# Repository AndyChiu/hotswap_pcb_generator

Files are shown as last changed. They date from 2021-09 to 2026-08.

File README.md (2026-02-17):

# 3D列印鍵盤熱插拔板產生器（網路線內芯線版本）

[原作者GitHub: 3D-Printable Hotswap Keyboard PCB Generator](https://github.com/50an6xy06r6n/hotswap_pcb_generator)

此專案為利用3D印表機，列印鍵盤底板、定位板、外殼..等部份來建構鍵盤，由於原作者使用22AWG電源線當主要線路，而我手邊有許多的廢棄網路線，所以就改用網路線內芯線來替代接線，並依照網路線內芯線的尺寸，修改了 switch.scad 的走線方式，因為線材較細，Row與Colum的線路可以走同一面，而不用怕交錯的部份太厚，所以把線路都改到正面走線。

另外也添加了不少種類的軸體，以及MCU等額外鍵盤用零件。

### 額外特性
- 支援多種軸體：Cherry MX-style、MX Low profile、Kailh Choc V1、Choc V2、Choc Mini、Gateron KS27、Gateron KS33 V3、Romer G、Redragon low profile、ALPS
- 單PCB可以放上多種不同軸體，layout.scad可以進行調整
- 支援多種MCU：ProMicro、ProMicro C、Elite C、Pico RP2040、RP2040 Zero
- 支援編碼器：EC11、EVQWGD001
- Choc V2 矮軸可以使用MX規格的衛星軸(穩定器)
- 支援4pin微動開關(microswitch)
- OLED座(0.96" 27.3x27.8mm)
- PCB板可針對外框進行設計，讓PCB板直接當作鍵盤使用
- Choc V1軸、MX軸、KS-27/KS-33與ALPS軸有固定架(holder)的選項可用，用於固定軸體，代替定位板的作用

### 曲面鍵盤設計
- 方式1: [UC36系列](https://github.com/AndyChiu/UC36)中，曲面鍵盤的相關程式與檔案，可由此[查閱](scad_UTP/Curved_PCB_KB)。
- 方式2: PCB板直接可以設定各別軸體的角度與高度，達到曲面鍵盤的效果。

### 限制
因著重在Kailh Choc等矮軸的使用與開發，矮軸上PCB板後高度較低，鍵帽通常也設計的較矮，因此較不易被撥動掉落，直接用 pcb.scad 產生 PCB 板即可使用，所以對於定位板、底板、外殼、墊高等程式檔都沒有更新，因此其他部份使用上可能會有點問題。

### 資料夾/檔案命名
由於對GitHub作業還不是很熟悉，且自己的改太多東西，所以不好直接更動原作者的檔案，因此目前先把自己處理的檔案與資料夾，都加上_UTP後綴字串，相關程式也有調整。

### 元件圖片

#### 軸座 (Switch base)

##### Cherry
| MX-style | MX Low profile |
| --- | --- |
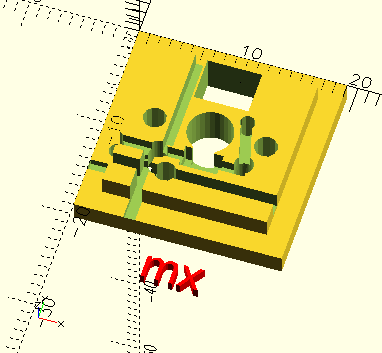
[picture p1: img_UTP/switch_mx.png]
MX
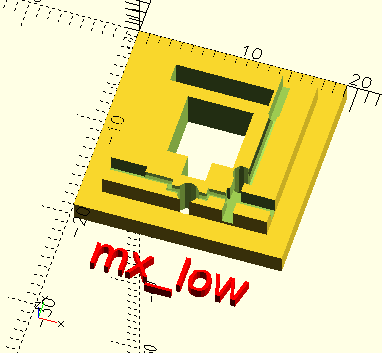
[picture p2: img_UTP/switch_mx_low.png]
MX_Low
| ||

##### Kailh Choc
| Choc V1 | Choc V2 | Choc Mini |
| --- | --- | --- |
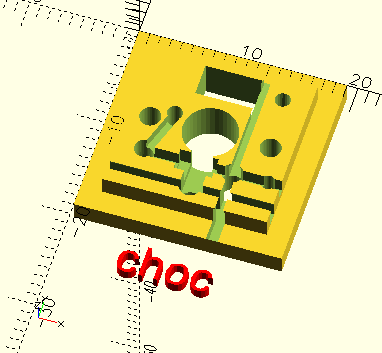
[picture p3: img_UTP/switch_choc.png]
choc
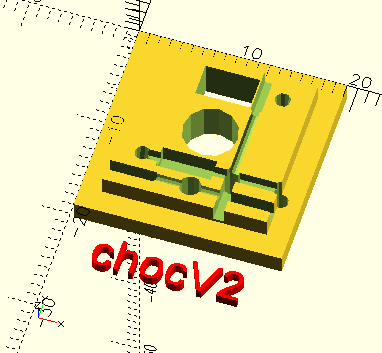
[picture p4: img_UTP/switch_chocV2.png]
chocV2
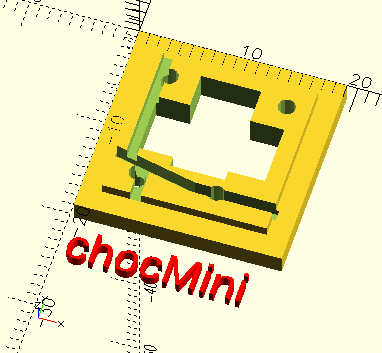
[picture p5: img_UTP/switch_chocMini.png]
chocMini
| |||

##### Kailh Choc
| Gateron KS27 | Gateron KS33 V3 |
| --- | --- |
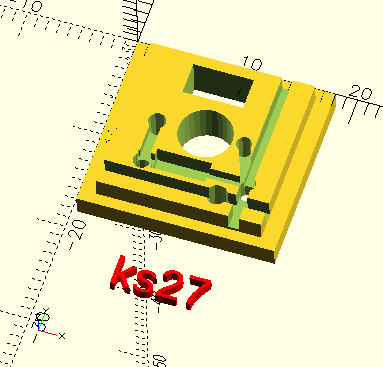
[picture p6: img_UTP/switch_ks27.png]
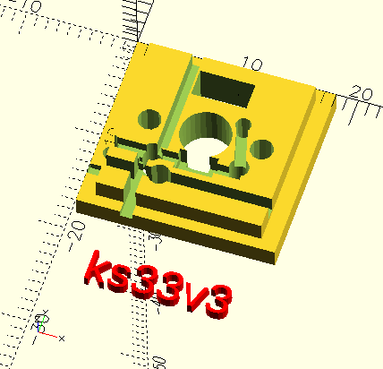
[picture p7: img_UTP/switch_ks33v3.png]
| ||

##### Other
| Romer G | Redragon low profile | ALPS |
| --- | --- | --- |
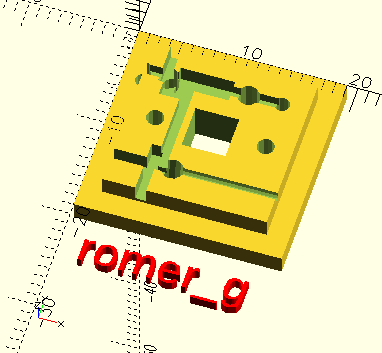
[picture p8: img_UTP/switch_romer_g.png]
Romer G
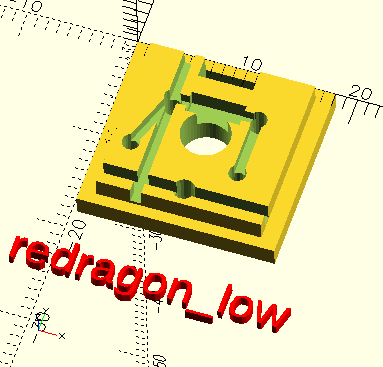
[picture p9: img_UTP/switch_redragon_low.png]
redragon_low
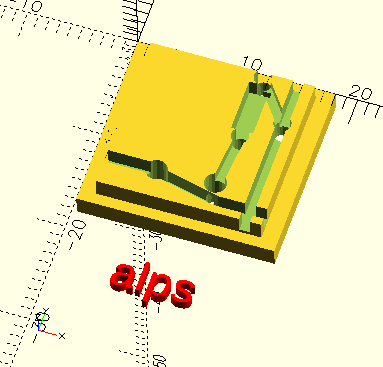
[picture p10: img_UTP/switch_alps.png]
||| |

##### 軸座含固定架
| Cherry MX-style1 | Cherry MX-style2 |
| --- | --- |
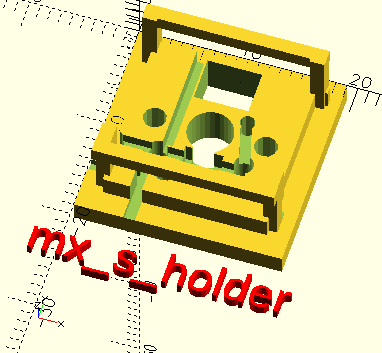
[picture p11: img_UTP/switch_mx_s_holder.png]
switch_mx_holder
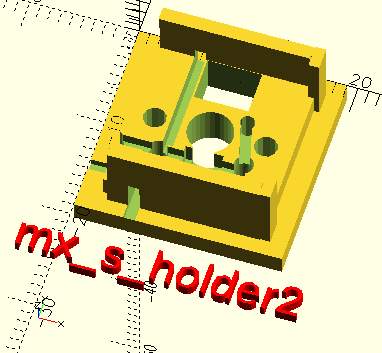
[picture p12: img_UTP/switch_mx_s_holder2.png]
switch_mx_holder
| | |

| Kailh Choc V1 | Gateron KS27| Gateron KS33v3 |
| --- | --- |  --- |
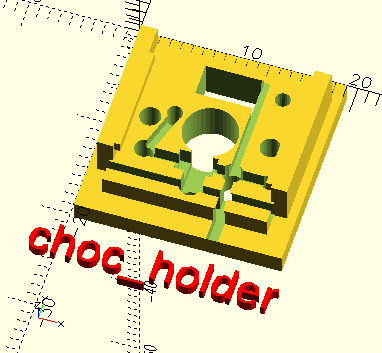
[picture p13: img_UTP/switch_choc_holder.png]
switch_choc_holder
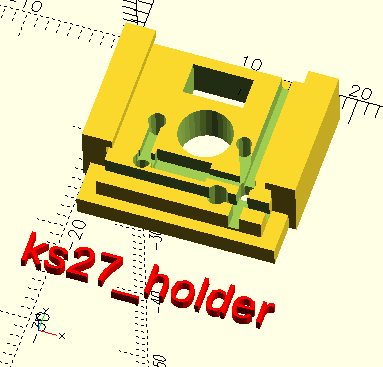
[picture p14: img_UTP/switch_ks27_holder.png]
switch_ks27_holder
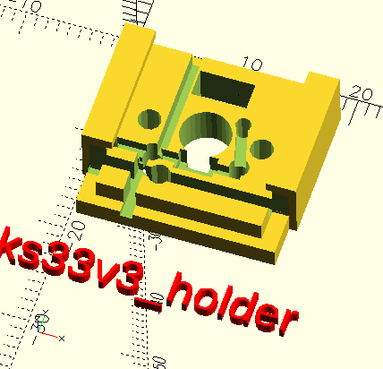
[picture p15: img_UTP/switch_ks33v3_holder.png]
switch_ks33v3_holder
||||

| Redragon low profile | ALPS|
| --- | --- |
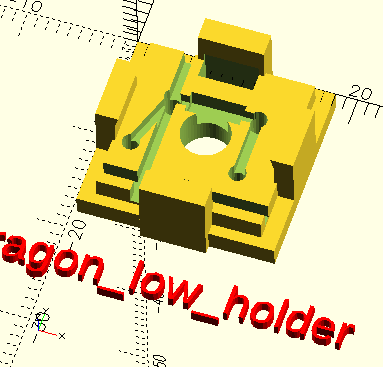
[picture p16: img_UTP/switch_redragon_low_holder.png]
redragon_low_holder
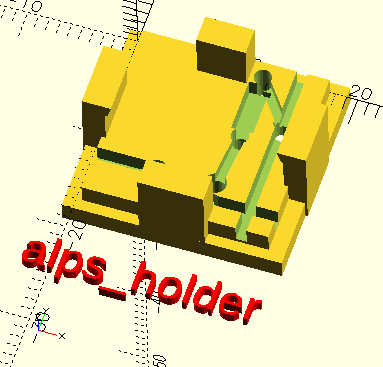
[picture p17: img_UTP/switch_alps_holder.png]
switch_alps_holder
|||

##### Dactyl類型使用的1U PCB
| Kailh Choc V2  |
| -------- |
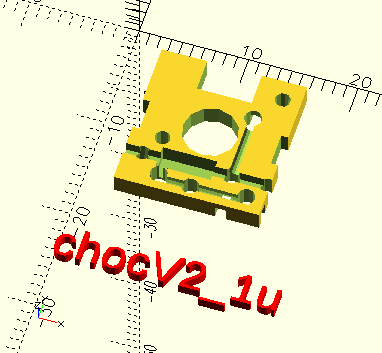
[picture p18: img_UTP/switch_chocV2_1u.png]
switch_chocV2_1u
| |

#### MCU

##### ProMicro

| ProMicro|ProMicro-C|Elite-C|
| --- | --- | --- |
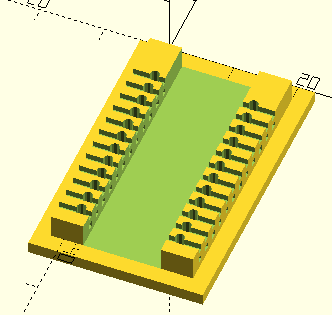
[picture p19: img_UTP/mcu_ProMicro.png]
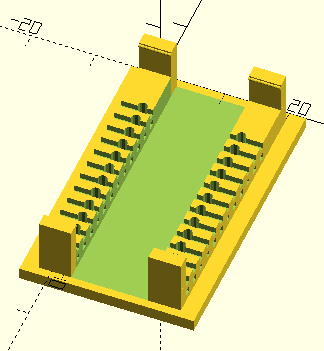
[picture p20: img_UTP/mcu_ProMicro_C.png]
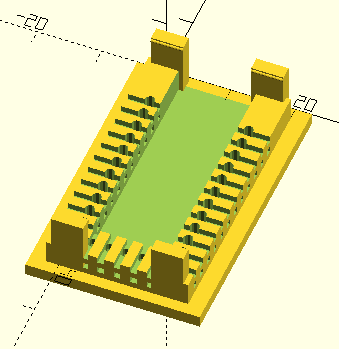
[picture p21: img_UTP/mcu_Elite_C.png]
| |||

##### RP2040

| RP2040 Pico|RP2040 Zero|
| --- |--- |
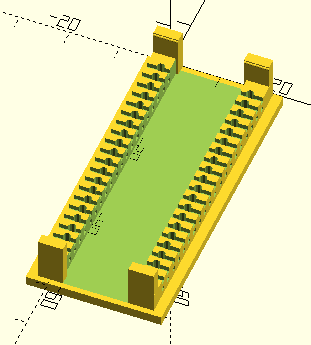
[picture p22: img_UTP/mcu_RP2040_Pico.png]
mcu_RP2040_Pico
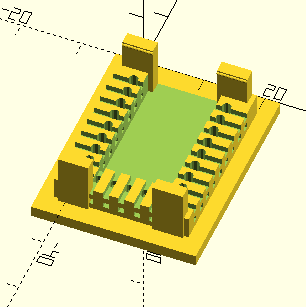
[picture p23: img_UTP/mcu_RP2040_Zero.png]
mcu_RP2040_Zero
| | |

#### 編碼器(Encoder)

|EC11|EVQWGD001|
| --- |--- |
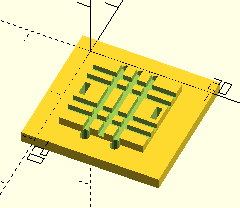
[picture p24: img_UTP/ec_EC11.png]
EC11
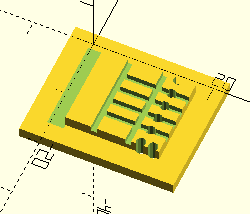
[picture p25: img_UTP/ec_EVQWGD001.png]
EVQWGD001
|||

#### 穩定器(Stabilizer)

|PCB(2u)|PCB Choc V2(2u)|Plate(2u)|
| --- | --- | --- |
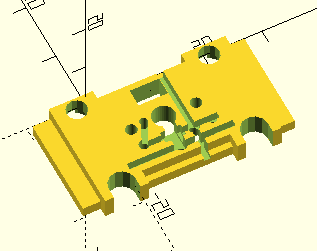
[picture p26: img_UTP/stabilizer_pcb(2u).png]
stabilizer_pcb(2u)
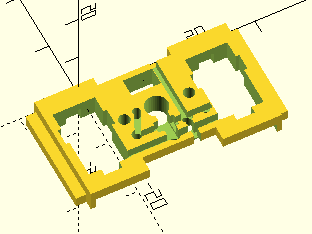
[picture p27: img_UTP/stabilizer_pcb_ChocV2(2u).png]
stabilizer_pcb_ChocV2(2u)
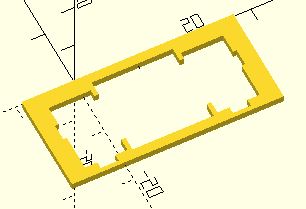
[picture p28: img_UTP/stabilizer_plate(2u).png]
stabilizer_plate(2u)
||||

#### TRRS
|PJ320A|PJ324M|
| --- | --- |
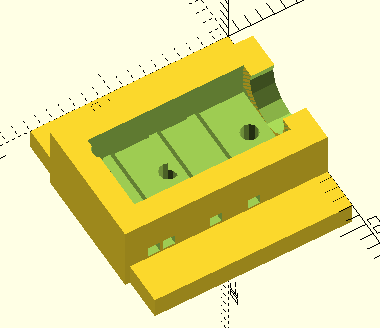
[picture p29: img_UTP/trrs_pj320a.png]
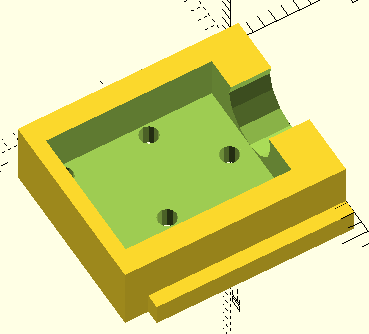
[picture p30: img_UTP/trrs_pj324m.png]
|||

#### 其他
|Micro Switch|OLED 0.96" 27.3x27.8mm|
| --- | --- |
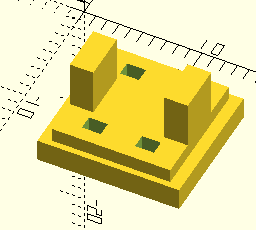
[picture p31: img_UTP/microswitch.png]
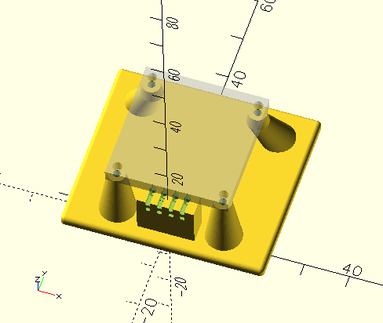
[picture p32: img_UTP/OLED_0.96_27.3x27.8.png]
|||

### 設計
可以優先參考原作者[設計指南(Design Guide)](https://github.com/50an6xy06r6n/hotswap_pcb_generator/blob/main/guide/design_guide.md)

修改版本的前期設計請參考（撰寫中）。

### 組裝
請參閱以下Blog:

[嘗試Choc V2矮軸與拉線教學](https://ie321mx.blogspot.com/2021/09/choc-v2.html)

[關於二極體版本的補充教學](https://ie321mx.blogspot.com/2021/09/blog-post.html)

原作者的[組裝指南(Build Guide)](https://github.com/50an6xy06r6n/hotswap_pcb_generator/blob/main/guide/build_guide.md)

### PCB板宣染圖
PCB板設計時，可以直接設計成曲面
PCB KB Curve Design1
PCB KB Curve Design2

F5宣染時，可以顯示設定的軸體與鍵帽，用來檢查各軸間是否有干擾的情況產生
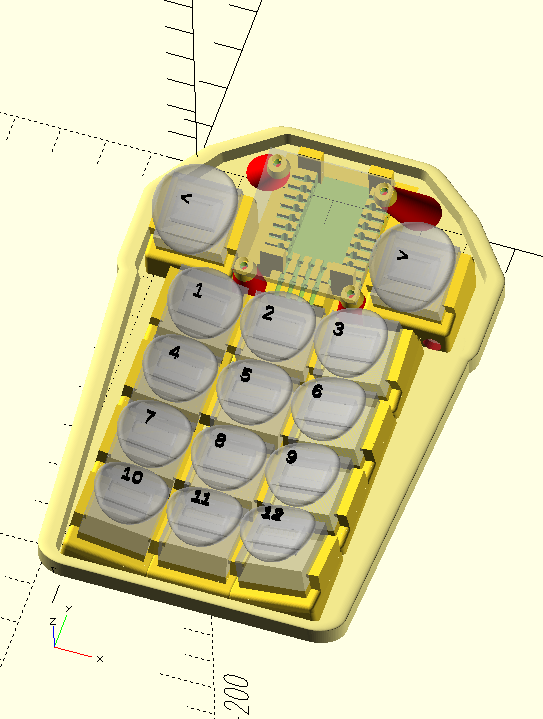
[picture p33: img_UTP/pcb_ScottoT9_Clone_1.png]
PCB - Scotto T9

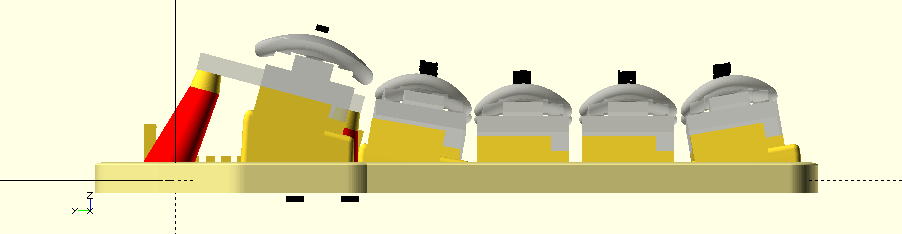
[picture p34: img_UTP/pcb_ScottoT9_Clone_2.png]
PCB - Scotto T9


### 照片集

印出的PCB曲面鍵盤
GMvE2cgXMAA4j0y

上軸體與鍵帽後
GMvKBvrWIAEK0nz

GMvKBzpXUAAMyPL

GMvKB7nXAAAX0QT

改良的EC11編碼器底座
EC11 Base

UC2 鍵盤 Choc V1 軸體 左手
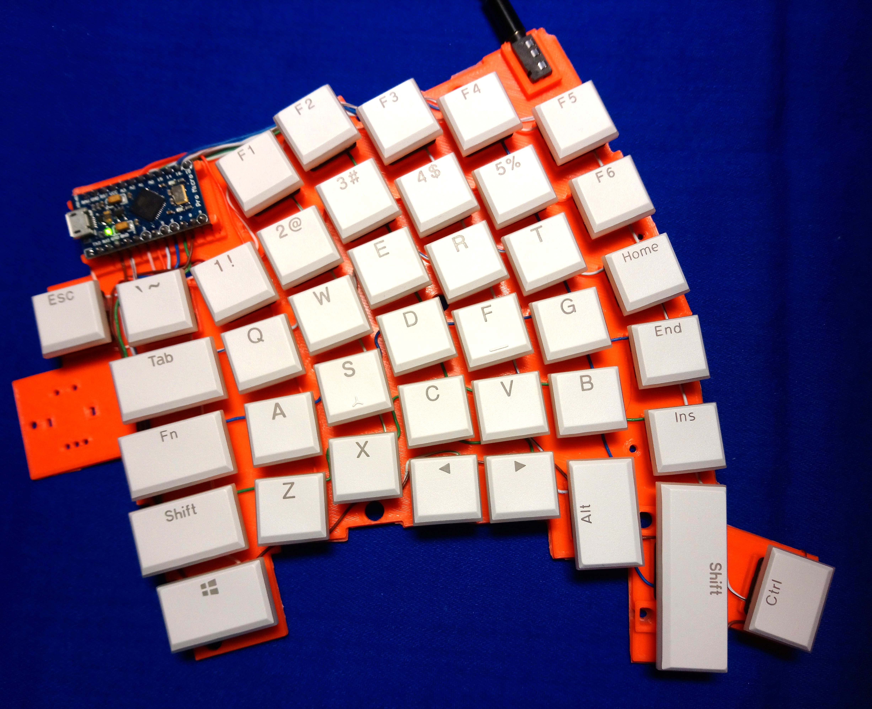
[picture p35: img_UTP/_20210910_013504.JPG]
UC2 Left Hand


UC2 鍵盤 Choc V1 軸體 右手
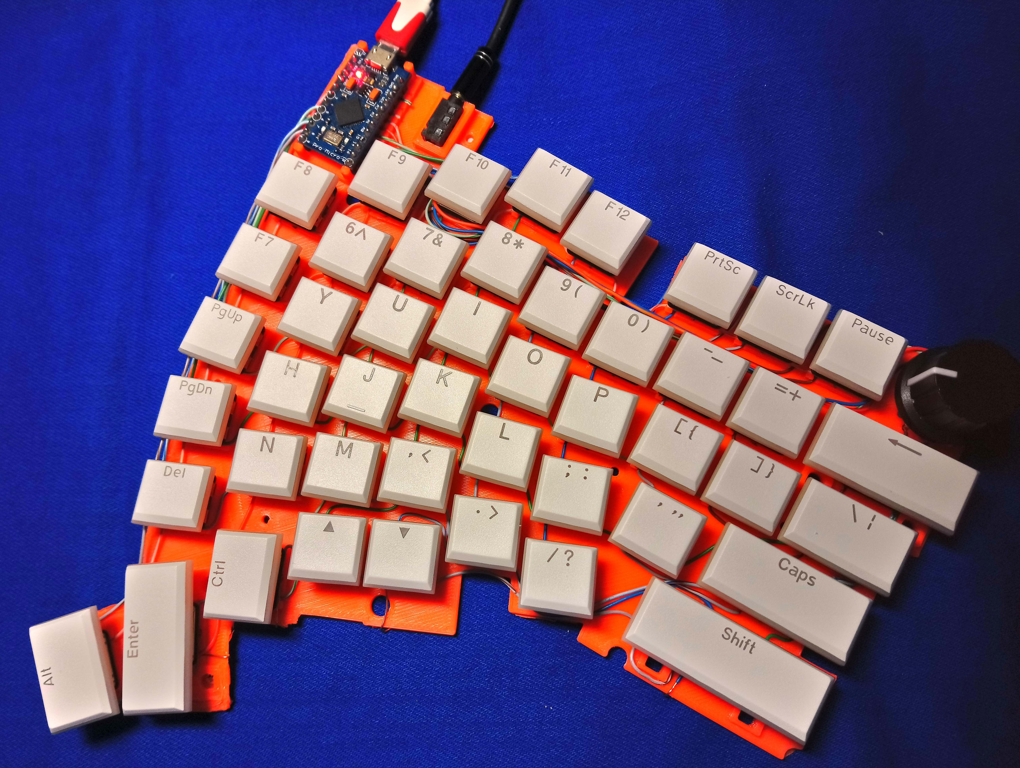
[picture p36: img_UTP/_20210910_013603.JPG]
UC2 Right Hand


EVQWGD001 編碼器
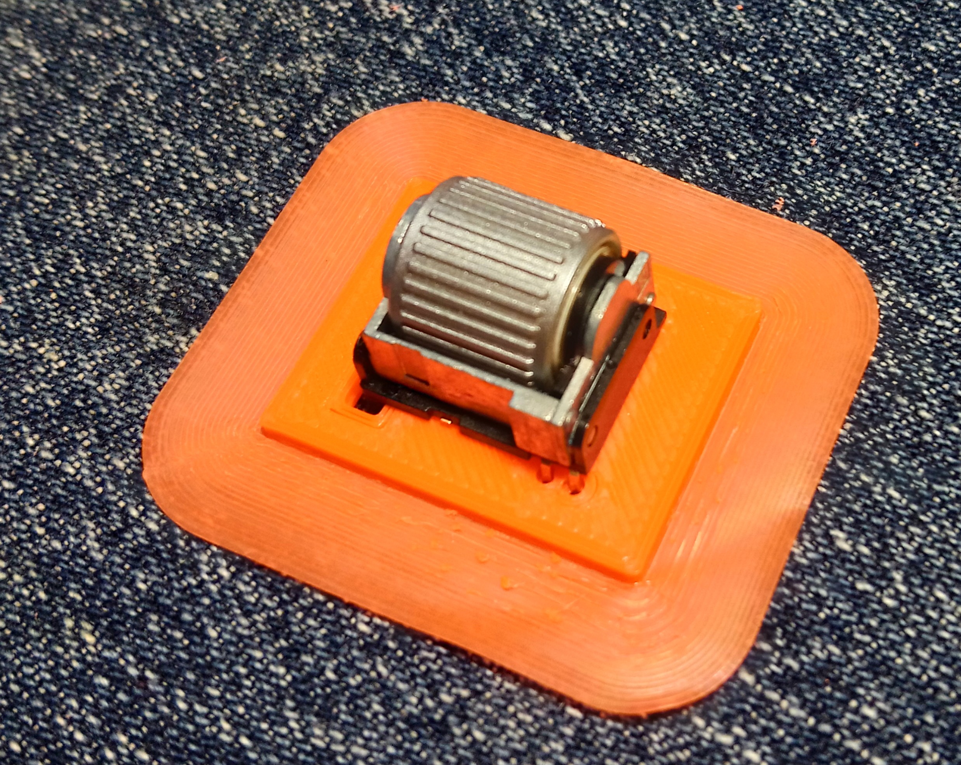
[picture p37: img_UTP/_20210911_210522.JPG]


Choc V1 + V2 軸共用座
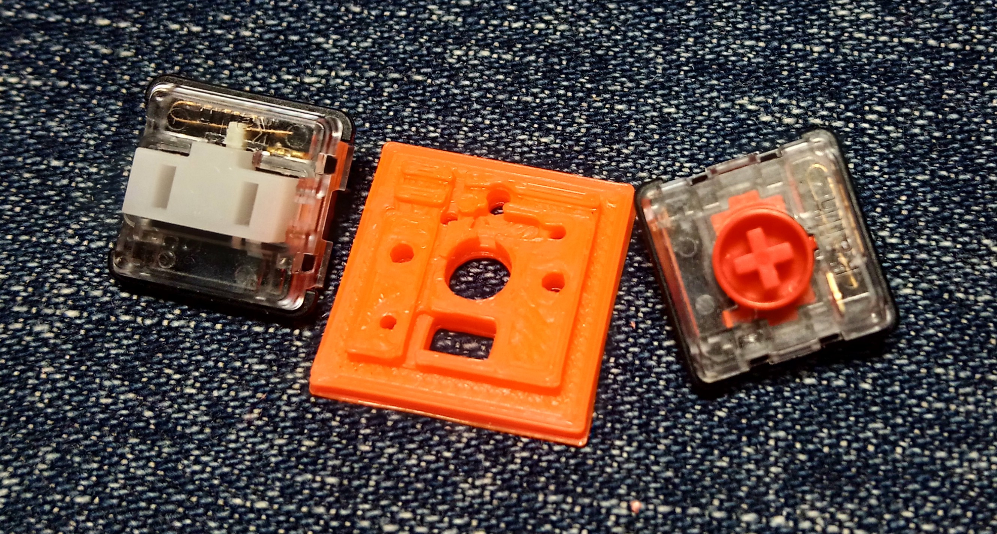
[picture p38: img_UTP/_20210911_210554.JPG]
Choc V1 + V2 Base


二極體接線後的狀態
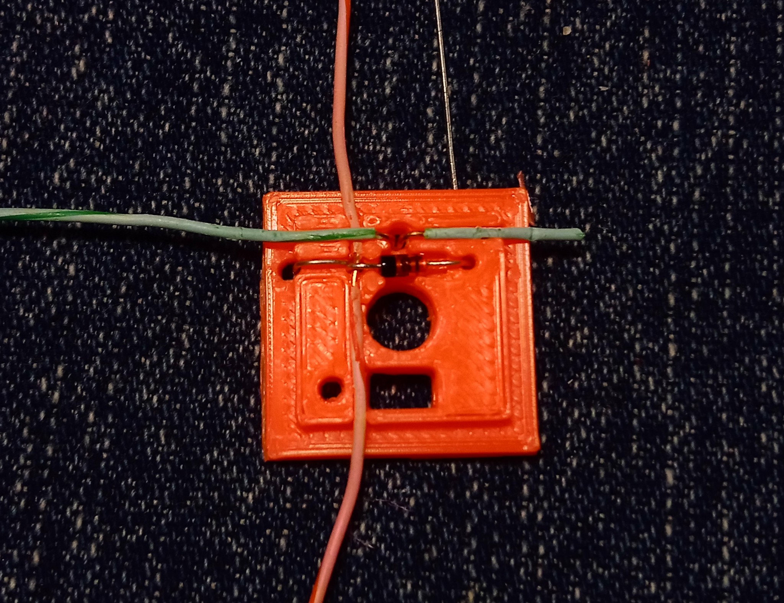
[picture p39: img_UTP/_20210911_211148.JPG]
Diode on Base


二極體接線後的狀態 背面
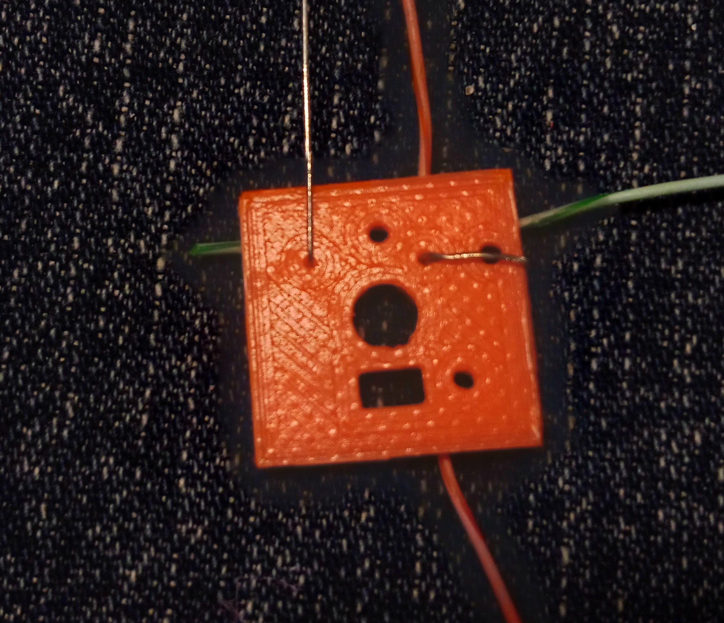
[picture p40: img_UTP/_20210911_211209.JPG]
Diode on Base back side


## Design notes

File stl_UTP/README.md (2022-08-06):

# STL檔案
這邊的STL僅展示現有的相關元件，這些元件都可以用在 layout.scad 上，可以由 pcb.scad 印出使用。

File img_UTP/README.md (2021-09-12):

*For Choc V1 & V2*
Choc V1 & V2

*Front wiring*
Front wiring

*Back wiring*
Back wiring

*Encoder roller Panasonic EVQWGD001*
Back wiring

*Keyboard Example Willow64+Extension with EC11 Encoder*
Right side
Left side

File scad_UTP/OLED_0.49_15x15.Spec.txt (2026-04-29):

/*
https://a.aliexpress.com/_mMWBdi1
0.49 Inch OLED Display LCD Module White 0.49" Screen 64x32 I2C IIC Interface SSD1306 Driver for Arduino AVR STM32

*/

[
    //OLED PCB
    [
        //OLED PCB Size [width,depth,height]
        //OLED_Size=
        [15, 15.5, 2.8],

        //OLED Pins
        //OLED_Pins=
        4,
        
        //OLED_Pin_Plastic_H=
        //OLED_Pin_Plastic_W=
        [2.6, 2.6],

        //OLED PCB Hole Distancia [x,y]
        //OLED PCB 四個鎖孔間距
        //OLED_Hole_Distancia=
        [15,15],

        //OLED PCB Hole Size 
        //OLED PCB板鎖孔尺寸
        //OLED_Hole_Size=
        0,
        
    ],

    //OLED PCB 位置偏移(與PIN位置)
    //OLED_Translate_Offset=
    [0, -0.7, 0],
    
    //Standoffs/Holder  墊高柱/支撐架
    [
        //OLED Standoff Offset [x,y]
        //OLED 支架整體偏移值 [x,y]
        //OLED_Standoff_Offset=
        [0,1.4],
        
        //base_pcb_layout_OLED_Standoff
        //LU,LD,RU,RD,
        //U,D,L,R
        //C
        [false, false, false, false, 
         false, false, false, false,
         false
         ],
    
        //base_pcb_layout_OLED_Holder
        //U,D
        [true, true],
    ]

]

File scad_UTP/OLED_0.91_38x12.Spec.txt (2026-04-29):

/*
https://es.aliexpress.com/item/1005006365845676.html
 I2C OLED Display Module 0.91 Inch I2C SSD1306 OLED Display Module 
 White / BLUE I2C OLED Screen Driver DC 3.3V~5V for Arduino
 
Note:
Do not reverse VCC and GND. This will cause damage to the OLED display.

Pin Description:
GND: Power Ground
VCC: Power + (DC 3.3 ~5v)
SCL: Clock Line
SDA: Data Line

Specification:
Model: SH-S091
Screen size: 0.91 inch
Interface: IIC
The main chip is: SSD1306;
Operating voltage: 3.3V~5.0V power supply.
Working Temperature: -30 degrees ~ 70 degrees
Display area: 22.384 x 5.584 (mm)
Physical size: 38 x 12 (mm)
Pixel size: 0.159 x 0.159 (mm)
Pixel pitch: 0.175 x 0.175 (mm)
Interface Type: IIC Interface
*/

[
    //OLED PCB
    [
        //OLED PCB Size [width,depth,height]
        //OLED_Size=
        [12, 38, 2.8],

        //OLED Pins
        //OLED_Pins=
        4,
        
        //OLED_Pin_Plastic_H=
        //OLED_Pin_Plastic_W=
        [2.6, 2.6],

        //OLED PCB Hole Distancia [x,y]
        //OLED PCB 四個鎖孔間距
        //OLED_Hole_Distancia=
        [12,35],

        //OLED PCB Hole Size 
        //OLED PCB板鎖孔尺寸
        //OLED_Hole_Size=
        0,
        
    ],

    //OLED PCB 位置偏移(與PIN位置)
    //OLED_Translate_Offset=
    [0, -0.7, 0],
    
    //Standoffs/Holder  墊高柱/支撐架
    [
        //OLED Standoff Offset [x,y]
        //OLED 支架整體偏移值 [x,y]
        //OLED_Standoff_Offset=
        [0,1.4],
        
        //base_pcb_layout_OLED_Standoff
        //LU,LD,RU,RD,
        //U,D,L,R
        //C
        [false, false, false, false, 
         false, false, false, false,
         false
         ],
    
        //base_pcb_layout_OLED_Holder
        //U,D
        [true, true],
    ]

]

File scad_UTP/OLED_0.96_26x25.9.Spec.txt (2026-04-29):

//0.96 inch IIC Serial 4pin White/Blue/Yellow Blue/Yellow OLED Display Module 128X64 12864 LCD Screen Board for arduino oled
//https://es.aliexpress.com/item/1005006262908701.html

[
    //OLED PCB
    [
        //OLED PCB Size [width,depth,height]
        //OLED_Size=
        [26, 25.9, 2.8],

        //OLED Pins
        //OLED_Pins=
        4,
        
        //OLED_Pin_Plastic_H=
        //OLED_Pin_Plastic_W=
        [2.6, 2.6],

        //OLED PCB Hole Distancia [x,y]
        //OLED PCB 四個鎖孔間距
        //OLED_Hole_Distancia=
        [22.5,22.5],

        //OLED PCB Hole Size 
        //OLED PCB板鎖孔尺寸
        //OLED_Hole_Size=
        2.1,
        
    ],

    //OLED PCB 位置偏移(與PIN位置)
    //OLED_Translate_Offset=
    [0, -0.2, 0],
    
    //Standoffs/Holder  墊高柱/支撐架
    [
        //OLED Standoff Offset [x,y]
        //OLED 支架整體偏移值 [x,y]
        //OLED_Standoff_Offset=
        [0,1.4],
        
        //base_pcb_layout_OLED_Standoff
        //LU,LD,RU,RD,
        //U,D,L,R
        //C
        [true, true, true, true, 
         false, false, false, false,
         false
         ],
    
        //base_pcb_layout_OLED_Holder
        //U,D
        [false, false],
    ]

]

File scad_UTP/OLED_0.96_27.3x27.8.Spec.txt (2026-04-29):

/*

Type: 0.96" Inch OLED Display Screen Module I2C IIC 128x64 SS - D - 1306 3.3V-5V Blue/blue Yellow/White
https://es.aliexpress.com/item/1005006700885056.html

    預留孔徑:
    螺絲直接鎖塑膠:
    預留孔徑：Ø 1.6 ～ 1.7 mm
    螺絲：M2 × 6 或 8 mm
    外柱直徑：Ø 4.5 ～ 5 mm

    熱熔銅螺母
    螺母外徑：通常 Ø 3.2 ～ 3.5 mm
    預留孔徑：Ø 3.0 mm
    孔深：≥ 3 mm

*/

[
    //OLED PCB
    [
        //OLED PCB Size [width,depth,height]
        //OLED_Size=
        [27.3, 27.8, 2.8],

        //OLED Pins
        //OLED_Pins=
        4,
        
        //OLED_Pin_Plastic_H=
        //OLED_Pin_Plastic_W=
        [2.6, 2.6],

        //OLED PCB Hole Distancia [x,y]
        //OLED PCB 四個鎖孔間距
        //OLED_Hole_Distancia=
        [23.5,23.5],

        //OLED PCB Hole Size 
        //OLED PCB板鎖孔尺寸
        //OLED_Hole_Size=
        2.1,
        
    ],

    //OLED PCB 位置偏移(與PIN位置)
    //OLED_Translate_Offset=
    [0, -0.7, 0],
    
    //Standoffs/Holder  墊高柱/支撐架
    [
        //OLED Standoff Offset [x,y]
        //OLED 支架整體偏移值 [x,y]
        //OLED_Standoff_Offset=
        [0,1.4],
        
        //base_pcb_layout_OLED_Standoff
        //LU,LD,RU,RD,
        //U,D,L,R
        //C
        [true, true, true, true, 
         false, false, false, false,
         false
         ],
    
        //base_pcb_layout_OLED_Holder
        //U,D
        [false, false],
    ]

]

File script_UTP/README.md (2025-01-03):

# KLE檔案轉換腳本 (KLE Conversion Script)

### 系統需求
需要安裝node.js v14以上版本

### 安裝方式 Install Dependencies

Windows:
```
install.bat
```
PS: 如有出現 npm 程式有更新，可以依照說明，使用 npm audit fix 來更新 npm

非Windows系統，請於命令列執行:
```
npm install
cd node_modules\@ijprest
npm install
cd ..\..\
```

### 執行腳本 Run script

#### 產生layout.scad:
預設為輸入檔名為 `layout.json`，輸出檔名為 `scad/layout.scad`，可以依照需求手動指定輸入與輸出檔名:
```
npm start -- <layout json file> <optional output filename>
```
#### 產生 .csv 檔案:
預設為輸入檔名為 `layout.json`，輸出檔名為原本檔名加上".csv"結尾，可以依照需求手動輸入layout檔名:
```
node Convert2csv.js <layout json file>
```

### 注意

如果輸出檔案已存在，將會覆蓋檔案，不會另外提醒，如已存在檔案，請先改檔名或者搬移到其他地方，然後再執行腳本。

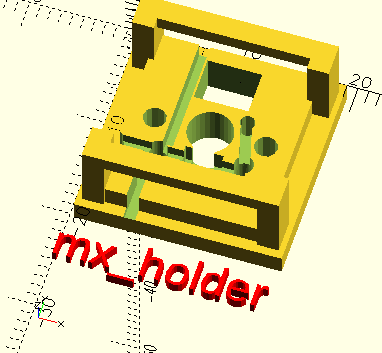
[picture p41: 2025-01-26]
img_UTP/switch_mx_holder.png

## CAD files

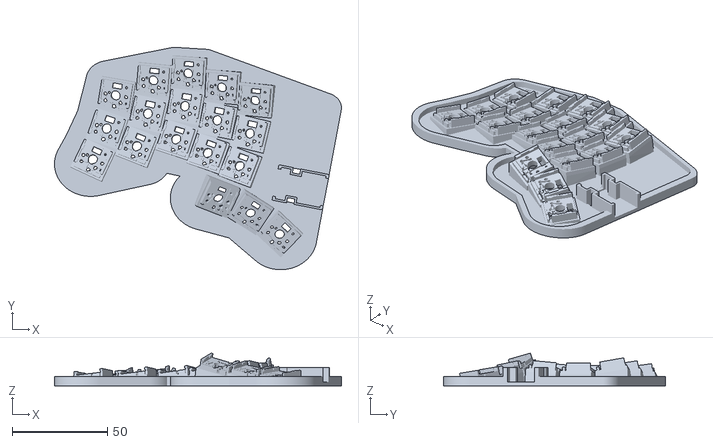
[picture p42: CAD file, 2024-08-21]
example_layouts_UTP/Willow-3x6+Esrille-thumb-3x1_(V2 Curve)/pcbWillow-3x6-Esrille-thumb-3x1(V2 Curve)_L.stl
150.7 x 116.7 x 17.2

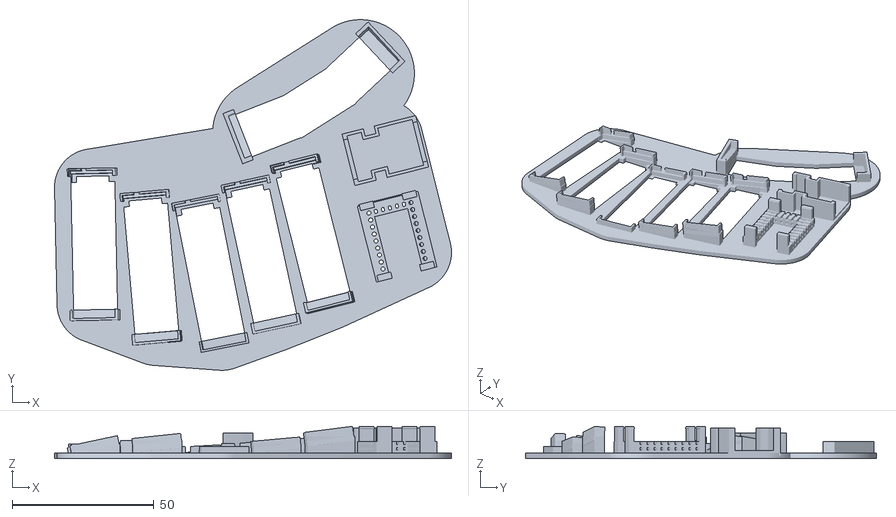
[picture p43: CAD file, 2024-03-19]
scad_UTP/Curved_PCB_KB/STL/11.3MM_LType/BasePlate_3U_11.3MM_LType_Right.stl
139.8 x 123.5 x 11.4

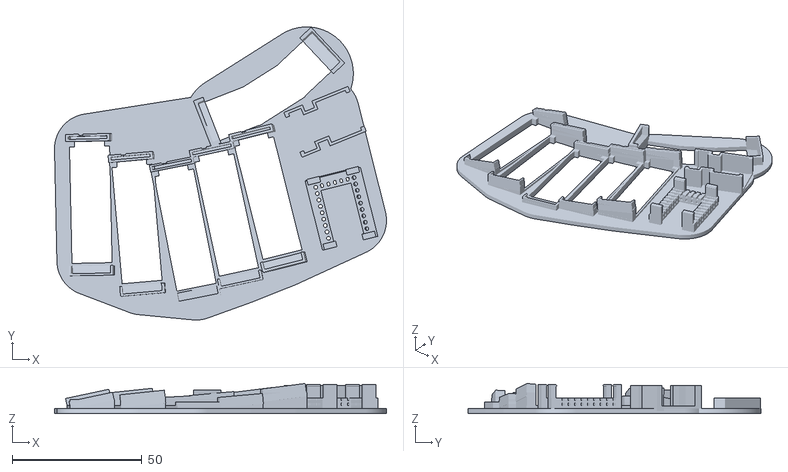
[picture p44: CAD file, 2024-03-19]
scad_UTP/Curved_PCB_KB/STL/13MM_MType/BasePlate_3U_16MM_MType_Right.stl
128.2 x 113.1 x 11.6

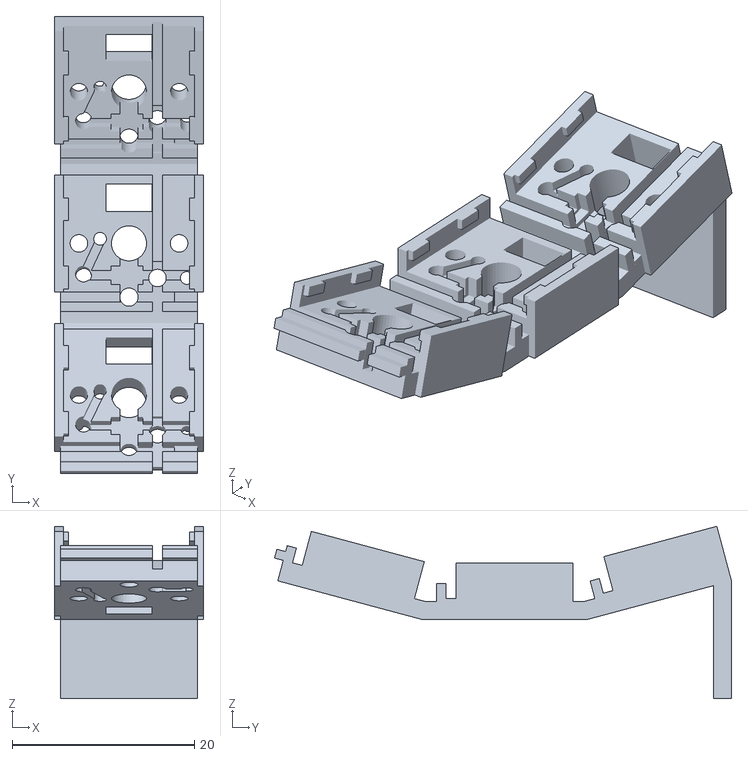
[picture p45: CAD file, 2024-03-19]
scad_UTP/Curved_PCB_KB/STL/16MM_LType/Curved_PCB(UC36_3U)_L_13mm.stl
16.4 x 50.2 x 18.9

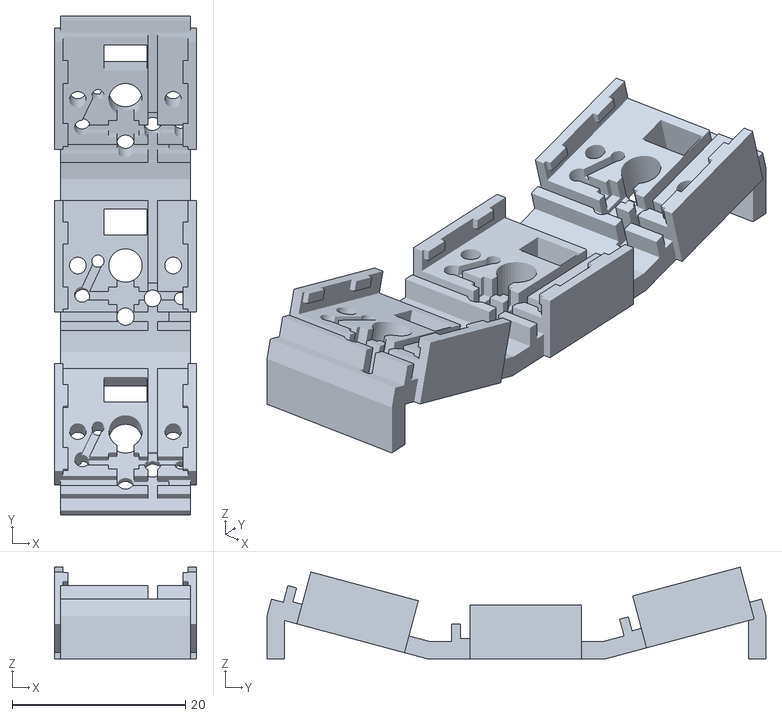
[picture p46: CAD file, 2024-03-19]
scad_UTP/Curved_PCB_KB/STL/16MM_MType/Curved_PCB(UC36_3U)_M_16.3mm.stl
16.4 x 57.6 x 10.6

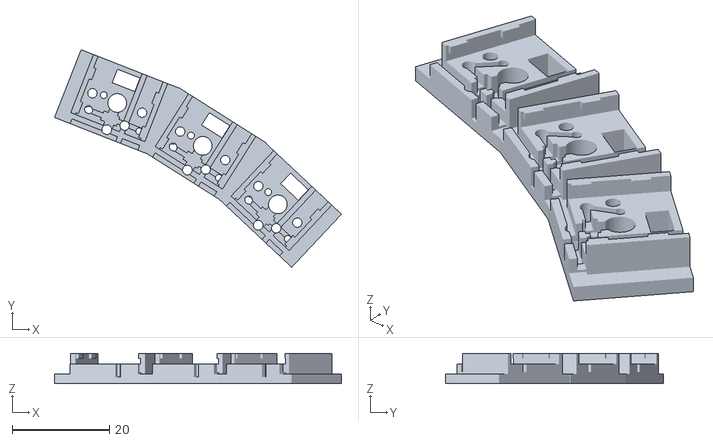
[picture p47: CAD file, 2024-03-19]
scad_UTP/Curved_PCB_KB/STL/18MM_LType/pcb_TH_18MM.stl
59.1 x 44.8 x 6.20

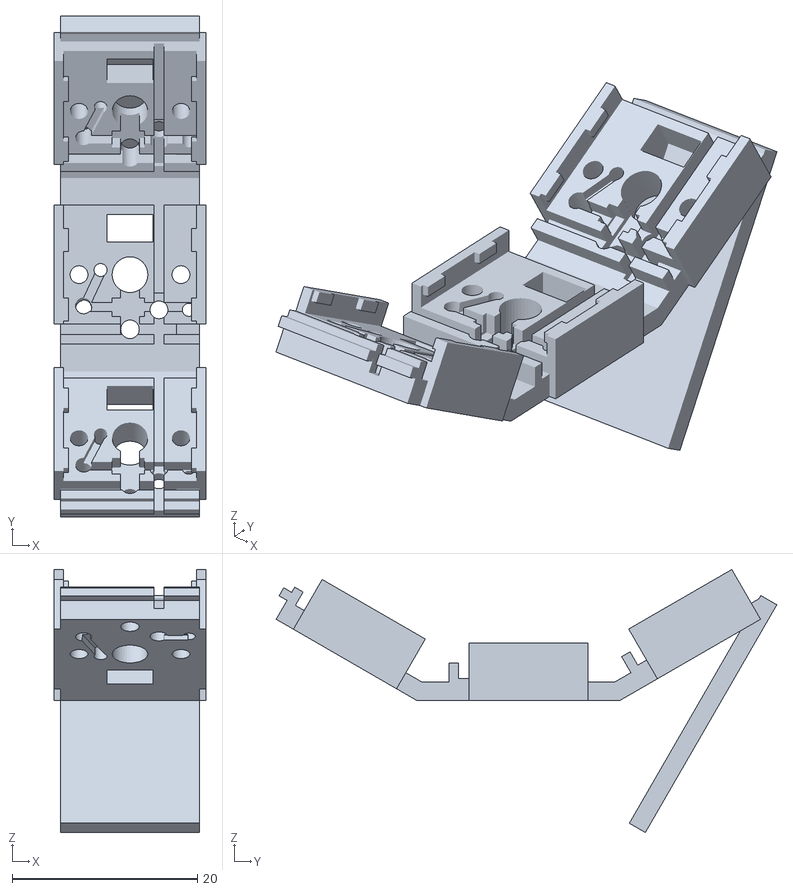
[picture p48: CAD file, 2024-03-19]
scad_UTP/Curved_PCB_KB/STL/Other/Curved_PCB(UC36_3U)_L_11.4mm_High.stl
16.4 x 54.0 x 28.4

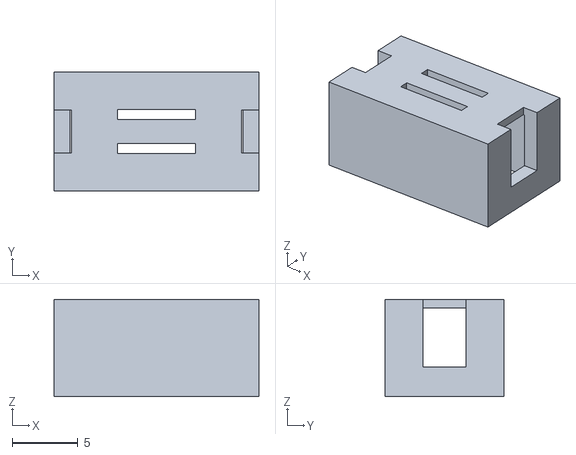
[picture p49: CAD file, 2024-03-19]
scad_UTP/IDC/STL/Male_idc.stl
15.6 x 9.05 x 7.41

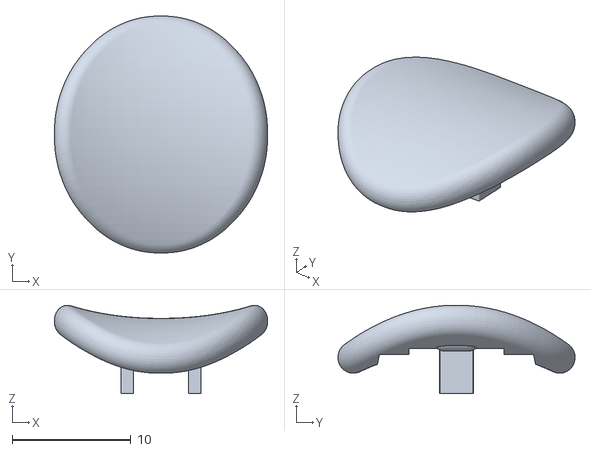
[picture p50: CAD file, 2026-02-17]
stl_UTP/Keycaps/Choc/AndyChiu/05_1010-20x18.stl
18.0 x 20.0 x 7.46

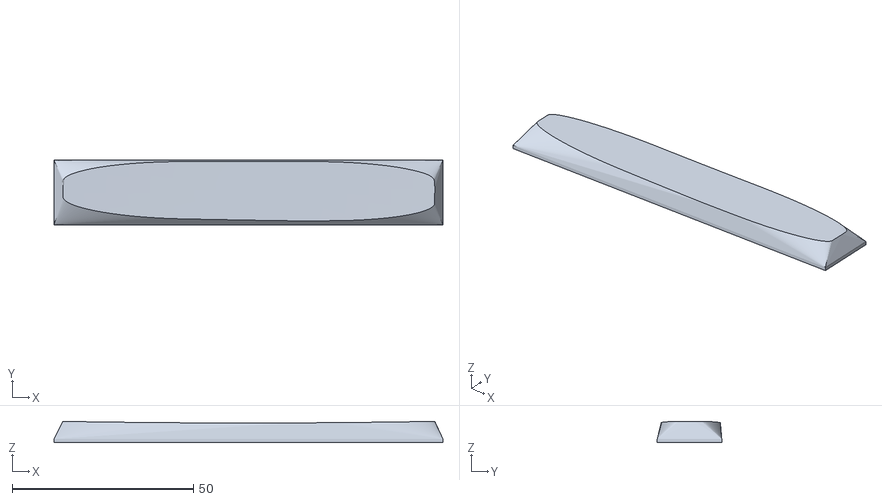
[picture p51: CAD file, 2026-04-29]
stl_UTP/Keycaps/MX/LP/LP_6U.stl
107.2 x 17.8 x 5.85

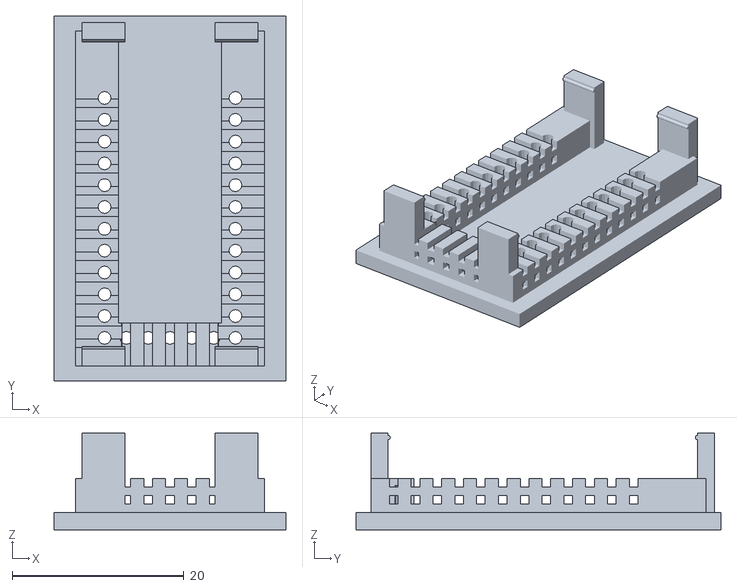
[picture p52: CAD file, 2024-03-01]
stl_UTP/MCU/mcu_Elite_C.stl
27.0 x 42.5 x 11.2

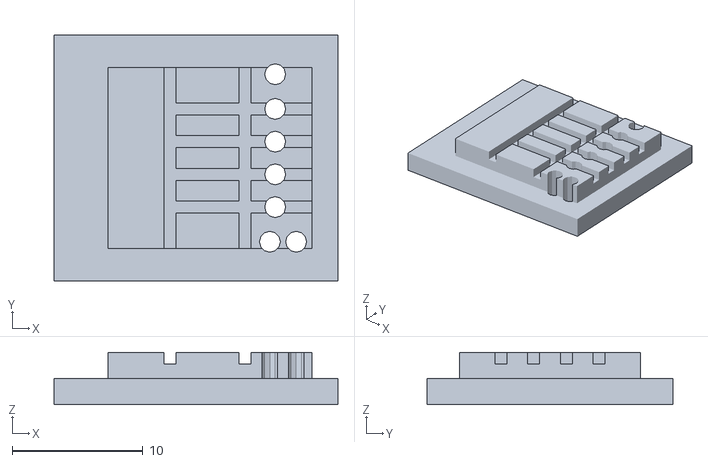
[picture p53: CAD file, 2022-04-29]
stl_UTP/Other/EVQWGD001.stl
21.7 x 18.8 x 4.00

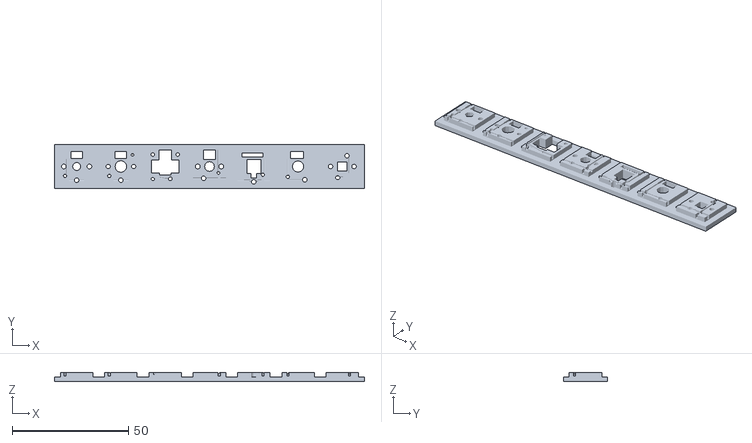
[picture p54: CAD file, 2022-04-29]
stl_UTP/switch-all7.stl
133.4 x 19.1 x 4.00

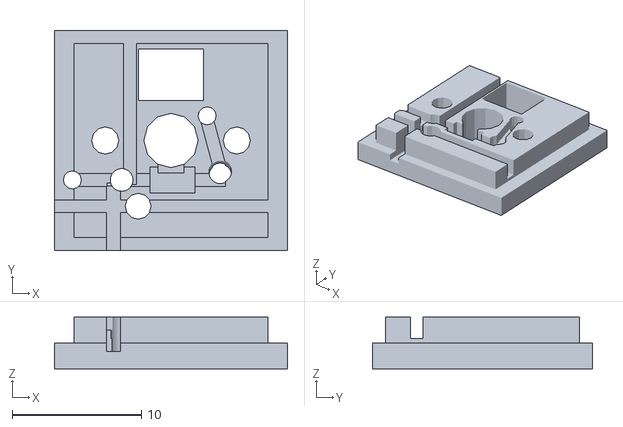
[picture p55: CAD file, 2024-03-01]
stl_UTP/Switch/switch_mx.stl
18.0 x 17.0 x 4.00

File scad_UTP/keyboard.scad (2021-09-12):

include <parameters.scad>
include <utils.scad>

use <backplate.scad>
use <pcb.scad>
use <plate.scad>
use <case.scad>

echo(str("Total thickness is ", total_thickness, "mm."));

translate([
    0,
    0,
    -plate_thickness/2 + pcb_plate_spacing + pcb_thickness
        + pcb_backplate_spacing + backplate_thickness
])
    if (case_type == "sandwich" || case_type == "backplate_case") {
        plate(switch_layout_final, mcu_layout_final, ec11_layout_final,  evqwgd001_layout_final, trrs_layout_final, plate_layout_final, stab_layout_final, standoff_layout_final);
    } else if (case_type == "plate_case") {
        case(switch_layout_final, mcu_layout_final, ec11_layout_final, evqwgd001_layout_final, trrs_layout_final, plate_layout_final, stab_layout_final, standoff_layout_final);
    } else {
        assert(false, "case_type parameter is invalid");
    }

translate([
    0,
    0,
    pcb_thickness/2 + pcb_backplate_spacing + backplate_thickness
])
    pcb(switch_layout_final, mcu_layout_final, ec11_layout_final, evqwgd001_layout_final, trrs_layout_final, stab_layout_final, standoff_layout_final, via_layout_final);

translate([
    0,
    0,
    backplate_thickness/2
])
    if (case_type == "sandwich" || case_type == "plate_case") {
        backplate(switch_layout_final, mcu_layout_final,ec11_layout_final, evqwgd001_layout_final, trrs_layout_final, plate_layout_final, stab_layout_final, standoff_layout_final);
    } else if (case_type == "backplate_case") {
        // Not implemented
    } else {
        assert(false, "case_type parameter is invalid");
    }
    

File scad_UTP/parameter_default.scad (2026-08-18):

//Keycap List
//鍵帽清單
include <parameters_keycaps.scad>

//Switch List
//軸體清單
include <parameters_switchs.scad>


/* PCB Parameters */
// Diameter of row/column wire channels
wire_diameter = 1;//0.91;
// Upward angle of switch pin in contact with diode anode (gives more reliable
// connections but slightly deforms pin)
diode_pin_angle = 5;  // [0:15]
// Amount the diode folds over
diode_foldover = 4;
// Overall thickness of PCB
pcb_thickness = 4;  // [4:0.1:10]

/* Switch Parameters */
// Switch type
// [mx, choc, chocV2, chocMini, ks27, ks33v3, mx_low, romer_g, redragon_low, alps]
// [choc_holder, chocV2_1u, mx_holder, mx_s_holder, mx_s_holder2, ks27_holder, ks33v3_holder, redragon_low_holder, alps_holder]
switch_type = "ks27_holder";

//Andy Add:

KeySwitch=
    switch_type == "choc" || switch_type == "choc_holder"
        ? ks_choc
    : switch_type == "chocV2" || switch_type == "chocV2_1u"
        ? ks_chocV2
    : switch_type == "chocMini"
        ? ks_chocMini
    : switch_type == "ks27" || switch_type == "ks27_holder"
        ? ks_ks27
    : switch_type == "ks33v3" || switch_type == "ks33v3_holder"
        ? ks_ks33v3
    : switch_type == "mx_low"
        ? ks_mx_low
    : switch_type == "redragon_low" || switch_type == "redragon_low_holder"
        ? ks_redragon_low
    : switch_type == "romer_g"
        ? ks_romer_g
    : switch_type == "alps" || switch_type == "alps_holder"
        ? ks_alps
        //Other allocations to MX
    : ks_mx;
    
    
// Switch orientation (based on LED location)
switch_orientation = "north";  // [north, south]
// Whether to use experimental diode leg contact
use_folded_contact = false;

// Andy Add:
// disable if usa use_folded_contact
// disable if wire_diameter > 1 (Only for UTP cable)
utp_wire = true;
led_hole = true;
diode_less = false;
choc_v1_compatible_v2  = true;
choc_v2_compatible_v1  = false;
both_deep_channels = true;
choc_row_hole = false;
choc_col_hole = false;


/* Stabilizer Parameters */
stabilizer_type = "pcb";  // [pcb, plate]


/* Case Parameters */
// Type of case to generate
case_type = "sandwich";  // [sandwich, plate_case, backplate_case]
// Thickness of case walls
case_wall_thickness = 2;
// Case wall draft angle
case_wall_draft_angle = 15;
// Width of the case chamfer (convex cases only)
case_chamfer_width = 1;
// Angle of the case chamfer (convex cases only)
case_chamfer_angle = 45;
// Height of the vertical portion at the bottom of the case 
// (not including backplate flange)
case_base_height = 2;
// Fit tolerance between interlocking case parts
case_fit_tolerance = 0.2;
// Tenting angle around x-axis
tent_angle_x = 0;
// Tenting angle around y-axis (i.e. typing angle)
tent_angle_y = 0;
// Point around which keyboard is tented
tent_point = [0,0];
//tent_point = [0,0];


/* Plate Parameters */
// Distance the plate sticks out past the PCB
plate_margin = 5;
// Radius of outer fillets
plate_outer_fillet = 2.5;
// Radius of inner fillets
plate_inner_fillet = 50;
// Setting this lower can help fix geometry issues when using custom plate shapes
// (i.e. two components that don't meet at exactly the same point can cause offset issues)
plate_precision = 1/100;


/* Backplate Parameters */
// Thickness of the backplate
backplate_thickness = 2;
// Thickness of flange around backplate if using an integrated-plate case
backplate_case_flange = 1;
// Spacing between the bottom of the PCB and the top of the backplate
pcb_backplate_spacing = 4;


/* MCU Parameters */
// [ProMicro, ProMicro_C, Elite_C,RP2040_Pico, RP2040_Zero]
//include <parameters_mcu_ProMicro.scad>
//include <parameters_mcu_ProMicro_C.scad>
//include <parameters_mcu_Elite_C.scad>
//include <parameters_mcu_RP2040_Pico.scad>
include <parameters_mcu_RP2040_Zero.scad>

mcu_type = "socketed3";  // [bare, socketed, socketed2, socketed3]

/* TRRS Socket Parameters */
// [RP2040_Pico, RP2040_Zero]
include <parameters_trrs_pj320a.scad>
//include <parameters_trrs_pj324m.scad>

/* Via Parameters */
via_width = 5;
via_length = 15;
via_shape = [via_width, via_length];


/* Standoff Parameters */
// Component the standoff is integrated with
standoff_integration_default = "plate";  // [plate, backplate, pcb, separate, none]
// Component the standoff is screwed to
standoff_attachment_default = "pcb";  // [plate, backplate, pcb, plate_backplate, none]
// Intermediate shape variable to pass around
standoff_config_default = [
    standoff_integration_default,
    standoff_attachment_default
];
// Diameter of integrated standoffs
standoff_diameter = 4.5;
// Diameter of standoff clearance hole
standoff_clearance_hole_diameter = 2.5;
// Diameter of standoff pilot hole
standoff_pilot_hole_diameter = 1.6;
// Diameter of standoff screw head counterbores
standoff_counterbore_diameter = 4.5;


/* Misc Parameters */
// Increase this if your standoffs are a bit too long due to printing tolerances
fit_tolerance = 0;
// Resolution of holes (affects render times)
$fn=12;


/* Advanced Parameters (related to switch size) */
// Switch spacing distance (19.05mm for MX keycaps,18mm for choc, 16mm for choc minimum spacing distance.)
unit = 19.05;
// Horizontal unit size (18mm for choc keycaps)
h_unit = 19.05;
// Vertical unit size (17mm for choc keycaps)
v_unit = 19.05;

//Andy add:
//unit size for stabilizer
unit_stb = 19.05;
h_unit_stb = 19.05;
v_unit_stb = 19.05;

unit_choc = 18;
h_unit_choc = 18;
v_unit_choc = 17;

choc_socket_size=ks_fraly[2][0];
fraly_socket_size=ks_fraly[2][0];

unit_ks27 = 18;
h_unit_ks27 = 18;
v_unit_ks27 = 17;

unit_redragon_low = 18;
h_unit_redragon_low = 18;
v_unit_redragon_low = 17;

ks27_socket_size=ks_ks27[2][0];

alps_socket_size=ks_alps[2][0];
alps_socket_size_w=16.4;
alps_socket_size_d=13.6-0.6;

redragon_low_socket_size=ks_redragon_low[2][0];
redragon_low_socket_size_w=14.5;
redragon_low_socket_size_d=13.8;

// Spacing of grid for MX pins
grid = 1.27;
// Size of socket body
socket_size =KeySwitch[2][0];

// Depth of the socket holes
socket_depth = 3.5;
// Thickness of the plate
plate_thickness =KeySwitch[2][1];

// Size of the plate cutout
plate_cutout_size =KeySwitch[2][2];

// Spacing between the top of the PCB and top of the plate
pcb_plate_spacing =KeySwitch[2][3];

// Align mcu to a unit
mcu_unit_resolution = .5;  // Grid size to snap to (as fractional unit)
mcu_h_unit_size = ceil(mcu_socket_width/mcu_unit_resolution/h_unit) * mcu_unit_resolution;
mcu_v_unit_size = ceil(mcu_socket_length/mcu_unit_resolution/v_unit) * mcu_unit_resolution;

// Total assembly thickness (for reference)
total_thickness =
    pcb_plate_spacing + pcb_thickness + pcb_backplate_spacing + backplate_thickness;

// Width of a border unit around the socket (for joining adjacent sockets)
border_width = (unit - socket_size)/2;
h_border_width = (h_unit - socket_size)/2;
v_border_width = (v_unit - socket_size)/2;

// Conversion factor from border width to mm (for use in layouts)
mm = 1/border_width;
h_mm = 1/h_border_width;
v_mm = 1/v_border_width;

// Andy Add:

total_travel=KeySwitch[2][4];

//Switch socket base
//軸座上的軸體扣夾
switch_socket_base_holder = false;

//扣夾是否支撐
switch_socket_base_holder_support_frame = false;

//TRRS
trrs_wire_channels_length = 16;
    
//Microswitch (reset button)
microswitch_hold_bar = false;
//    
//右側位移
iRSOffSet=0.2;
iRSOffSet2=iRSOffSet*h_unit_stb;


/* 
   ====================================================   
   == PCB keyboardization design /PCB 鍵盤化設計 ========
   ====================================================   
*/   


//Mark out PCB layout design points set, no hull the objects.
//將外圍設定的點標註出來,不產hull畫面: true, false, "DontShow"
base_pcb_layout_outer_DesignMode = false;
DesignMode_deep=0;

//What color should be displayed when the outer hull is surrounded
//外圍hull包圍起來時，要產生什麼顏色: "ColorName"(顏色名稱),"None"(不產生顏色),"Group"(群組第一個點的顏色)
base_pcb_layout_outer_hull_color = "None";

//Mark out the grooves of the circular self-adhesive rubber pad
//將圓形自黏膠墊凹槽標註出來
base_pcb_layout_Rubber_Pads_DesignMode = true;

//No cutout the switch socket hole, which can increase the view speed
//不挖軸坐上的洞，可以增加速檢視速度
base_pcb_layout_DesignMode = true;

//Draw an outer frame
//是否繪製外框: "Basic"(基本), "RoundedCorners"(圓角), false (不繪製)
base_pcb_layout_outer_EdgeFrame = "RoundedCorners";

//apply the setting of the Switch angle and height(3D-shaped)
//是否套用軸體角度與高度的設定(立體化)
base_pcb_layout_ApyAdjSwitchAngleAndHeight = true;

//Non-Border on 3D-shaped mode?
//立體化後是否不繪製軸的Borders？
base_pcb_layout_IfAdjSwitchAngleAndHeight_NoBorders =false;

//Raised Switch Base Style
//凸起的軸座樣式 "Basic"(基本), "RoundedCorners"(圓角)
base_pcb_layout_RaisedSwitchBaseStyle= "RoundedCorners";

//No increase in internal cavity
//不擴大突起軸座的內部空腔,值: true , false, "1U"
base_pcb_layout_NoIncreaseInInternalCavity=true;

//PCB board circuit hole
//PCB板開線路孔洞 ,值: true , false
base_pcb_layout_Use_Cable_Hole= true;

/* Preview mode */

//Show virtual KeySwitch in preview?
//預覽時是否顯示虛擬軸體?
base_pcb_layout_ShowVKeySwitch = true;
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

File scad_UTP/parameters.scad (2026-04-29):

include <parameter_default.scad>

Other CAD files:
example_layouts_UTP/Willow-3x6+Esrille-thumb-3x1_(V2 Curve)/pcb_Willow-3x6-Esrille-thumb-3x1_(V2 Curve)_R.stl
scad_UTP/Curved_PCB_KB/STL/11.3MM_LType/BasePlate_3U_11.3MM_LType_Left.stl
scad_UTP/Curved_PCB_KB/STL/13MM_MType/Curved_PCB(UC36_3U)_M_13mm.stl
scad_UTP/Curved_PCB_KB/STL/16MM_LType/BasePlate_3U_16MM_LType_Left.stl
scad_UTP/parameters_keycaps.scad
example_layouts_UTP/Willow-3x6+Esrille-thumb-3x1_(V2 Curve)/layout_Willow-3x6+Esrille-thumb-3x1_(V2 Curve)_L.scad
example_layouts_UTP/Willow-3x6+Esrille-thumb-3x1_(V2 Curve)/layout_Willow-3x6+Esrille-thumb-3x1_(V2 Curve)_L2.scad
example_layouts_UTP/Willow-3x6+Esrille-thumb-3x1_(V2 Curve)/layout_Willow-3x6+Esrille-thumb-3x1_(V2 Curve)_R.scad
example_layouts_UTP/Willow-3x6+Esrille-thumb-3x1_(V2 Curve)/layout_Willow-3x6+Esrille-thumb-3x1_(V2 Curve)_R2.scad
example_layouts_UTP/crkbd/layout_corne36_L.scad
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

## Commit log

2021-09-12 add new SCAD for UTP Wire
    [backplate.scad, case.scad, default_layout.scad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]
2021-09-12 add .stl and .jpg for example
    [EVQWGD001.stl, ec11.stl, switch_Choc_V1&2.stl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]
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2021-09-13 clean temp layout
    [layout-1.scad]
2021-09-21 add support Elite-C MCU
    [default_layout.scad, mcu.scad, parameters.scad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]
2021-09-21 add Reset button(TEST)
    [ResetButton.scad]
2021-09-22 add ResetButton halder
    [ResetButton.scad]
2021-09-23 chg ResetButton to microswitch
    [microswitch.scad]
2021-10-11 add Gateron KS-27 Switch support
    [parameters.scad, switch.scad]
2021-10-13 add stabilizer for ChocV2(use MX plate cutout)
    [stabilizer.scad, switch.scad]
2021-10-14 bug fix ks27 and micro-switch
    [default_layout.scad, microswitch.scad, pcb.scad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]
2021-10-17 fix MicroSwitch holder
    [microswitch.scad]
2021-11-06 add mx low profile switch(LED & DL)
    [parameters.scad, switch.scad]
2022-02-06 Add Romer-G Switch support Modify Stabilizer for KS27
    [parameters.scad, stabilizer.scad, switch.scad]
2022-04-29 add chocMini switch support and change switch_socket module, add use_switch_type parameter
    [ec11.stl, mcu.stl, stabilizer.stl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]
2022-05-01 modify index.js for change layout.scad default structure
    [parameters.scad, pcb.scad, switch-chocmini&dl.stl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]
2022-05-15 mcu add socketed2
    [default_layout.scad, mcu.scad, microswitch.scad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]
2022-08-05 add new switch type 'redragon_low'
    [mcu.scad, parameters.scad, switch.scad]
2022-08-05 change parameters.scad, move mcu part to external file
    [parameters_mcu_Pico_RP2040.scad, parameters_mcu_ProMicro.scad, parameters_mcu_ProMicro_C.scad]
2022-08-05 add lost files
    [parameters_mcu_Elite_C.scad]
2022-08-05 add some socket_cutou
    add chocMini_socket_cutout_led & redragonlow_socket_cutout_led
    [switch.scad]
2024-02-29 大量更新
    精進Choc V1的二極體座的布局
    新增PCB上的軸體固定夾，可以固定軸體而不需要定位板
    分拆parameters內，關於MCU與TRRS的內容到獨立的檔案
    Layout的設定可以單獨設置不同類型的軸體
    [default_layout.scad, mcu.scad, parameters.scad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]
2024-03-01 upload redragon_low png
    [parameters.scad, switch_List.SCAD]
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2024-03-01 update stl files
    [EVQWGD001.stl, ec11.stl, mcu.stl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]
2024-03-04 針對PCB外框美化
    layout 新增 base_pcb_layout_outer 參數
    ，可畫出指定範圍的hull並且合併起來，用來美化PCB外框的部分
    [default_layout.scad, mcu.scad, pcb.scad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]
2024-03-19 整合 曲面鍵盤 相關程式
    包含曲面鍵盤PCB與底板程式、IDC接頭相關程式、PCB底板增加外框設計與突起邊框設計
    [BasePlate.SCAD, BasePlate_3U_11.3MM_LType_Left.scad, BasePlate_3U_11.3MM_LType_Left.stl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]
2024-05-09 Update ec11.scad
    EC11基座改進
    [ec11.scad]
2024-05-09 Update mcu.scad
    MCU基座改進
    [mcu.scad]
2024-05-09 Update parameters_mcu_RP2040_Zero.scad
    RP2040 Zero固定住的間距，調整成0，減少晃動，如果卡不進去，可能檢查一下MCU的PCB版，是否裁切時有凸出的部分，可用銼刀磨平
    [parameters_mcu_RP2040_Zero.scad]
2024-05-09 穩定器程式改良
    穩定器增加了針對軸體旋轉時的調整，還有unit變更時，穩定器間距會跟著改變的問題。
    [stabilizer.scad, stabilizer_spacing.scad]
2024-05-09 PCB板鍵盤化相關設計更新，新增曲面鍵盤設計功能
    針對PCB板直接當作鍵盤使用的情境，加入鍵盤化的要素，包含底板設計、外框、內凹文字、外凸文字、自黏防滑膠墊凹槽..等設計。
    新增曲面鍵盤設計，針對每個軸體可進行角度調整、增加高度，並加入虛擬軸體、鍵帽與文字，以便於查看設計結果。
    [default_layout.scad, parameters.scad, pcb.scad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]
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2024-05-09 曲面 PCB KB 範例 Layout 檔案
    曲面 PCB KB 範例 Layout 檔案
    Willow-3x6+Esrille-thumb-3x1_(V2 Curve)
    [layout_Willow-3x6+Esrille-thumb-3x1_(V2 Curve)_L.scad, layout_Willow-3x6+Esrille-thumb-3x1_(V2 Curve)_R.scad, parameters.scad]
2024-05-23 hull後顏色能依照群組顯示
    [parameters.scad, pcb.scad, utils.scad]
2024-08-21 增加範本PCB的 .stl 檔案
    [pcb_Willow-3x6+Esrille-thumb-3x1_(V2 Curve)_L.stl, pcb_Willow-3x6+Esrille-thumb-3x1_(V2 Curve)_R.stl]
2024-11-19 新增軸體參數bod
    bod(Base Offset direction): C,U,D,L,R,LU,LD,RU,RD
    C=Center, LU=Left-Up, RD=Right-Down,..etc.
    可用於挖通軸體群，增加範例檔案
    [ec11.scad, ec11_cover.scad, layout_Willow-3x6+Esrille-thumb-3x1_(V2 Curve)_L.scad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]
2024-11-22 Curved_PCB 相關程式更新
    [BasePlate.SCAD, BasePlate2_3U_18MM_LType_Left.scad, BasePlate_3U_11.3MM_LType_Left.scad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]
2024-11-25 新增 ks27_holder 項目
    [mcu.scad, parameters.scad, switch.scad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]
2024-12-19 修改layout.scad結構
    鍵的尺寸加上長度(key.height),以便虛擬鍵帽檢查時使用
    [parameters.scad, switch.scad, utils.scad]
2024-12-19 修正utils.scad
    修正bodx與body計算錯誤問題
    [utils.scad]
2024-12-19 修改Curved_PCB_KB
    [BasePlate.SCAD, BasePlate2_3U_18MM_LType_Left.scad, BasePlate_POS_02.scad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]
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2025-01-03 update example layout
    [layout_Willow-3x6+Esrille-thumb-3x1_(V2 Curve)_L.scad, layout_Willow-3x6+Esrille-thumb-3x1_(V2 Curve)_L2.scad, layout_Willow-3x6+Esrille-thumb-3x1_(V2 Curve)_R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]
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2025-01-03 rename example .stl files
    [pcbWillow-3x6-Esrille-thumb-3x1(V2 Curve)_L.stl, pcb_Willow-3x6-Esrille-thumb-3x1_(V2 Curve)_R.stl]
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2025-01-26 fix pcb.scad bug
    [pcb.scad]
2025-06-05 Update utils.scad
    修正平面鍵盤顯示虛擬軸與虛擬鍵帽異常的問題。
    新增base_pcb_layout_NoIncreaseInInternalCavity參數的運用
    [utils.scad]
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2025-06-06 Update parameters.scad
    add base_pcb_layout_Use_Cable_Hole
    [parameters.scad]
2025-06-06 Update pcb.scad
    add pcb_layout_Cable_Hole
    [pcb.scad]
2026-02-17 年度更新
    新增/更新 Choc V1, Choc V2, Gateron KS33v3, Redragon low, ALPS 等軸座
    虛擬鍵帽 - 新增使用.stl檔案功能
    虛擬軸體 - 更細緻化
    提供自製鍵帽.stl檔案
    增加OLED座選項
    [02-CF-T1-01.stl, 02-CF-T2-01.stl, 05-16x16.stl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]
2026-04-29 檔案架構變更與許多更新
    設定檔案結構改變:
    解決長久以來的痛點，原程式要切換處理的鍵盤十分繁瑣，現在透過架構修改，layouts.scad 與 parameters.scad 只存設定檔清單，可手動以雙斜線方式(//)將沒用到的標記起來(Ctrl+D)，只開一個要使用(Ctrl+Shift+D)，然後存檔，即可快速切換鍵盤layout與參數設定，這可便於快速切換要處理的鍵盤。
    轉檔程式更新(index.js):
    因應架構上的修改，轉檔程式也跟著修改，可檢查是否已存在layout檔案，如存在時會詢問「(1) 重新命名舊檔案並儲存新檔 (2) 直接覆蓋」，之後會再詢問是否新增參數檔案，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
    [LP_1.25U.stl, LP_1.5U.stl, LP_1.5UL.stl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]
2026-05-04 修正部分錯誤
    mcu.scad:
    module socketed_mcu3 內容調整,，以便能更包覆MCU板，避免脫落
    pcb.scad:
    調整 pcb_layout_IDC_Hole 的部份，將裁切提前至產生PCB外圍框架後，以避免後續放上零件時被切到
    [mcu.scad, pcb.scad]
2026-05-18 Adjust EC11 socket cutout & PCB hole handling
    Increase and tweak EC11 cutout geometry for better clearance and additional cutouts: enlarge several cube cutouts, add a lower-left rotated cut, add more small translated cube cuts, change one fixed-seat cube to commented state, and increase polyhole radius from 0.8 to 0.9. Update pcb.scad hole renderer to distinguish hole types ("cylinder" vs "cube") and handle cube dimensions, and guard rubber-pad rendering with an extra point field check. Update script_UTP/index.js documentation to reflect the new base_pcb_layout_Cable_Hole format (Type + extra data) and provide example usage.
    [ec11s_diode.scad, pcb.scad]
2026-08-18 Add Fraly switch support and poly utilities
    Add support for Fraly switches: new ks_fraly parameters, fraly_socket_size, fraly switch/holder modules and fraly_socket_cutout_led; update switch lists to include "fraly"/"fraly_holder". Introduce poly* utility helpers (polyline, polycube, polypoint, polyhole, polydiode) and fixes (polycube ds_offset, polyhole_cube h param). Make MCU tweaks: optional second wire channels flag and several geometry adjustments. Use ks_* arrays for socket sizes (ks27/alps/redragon_low/fraly). Minor PCB rendering/comment fixes and other numeric cutout refinements.
    [mcu.scad, parameter_default.scad, parameters_mcu_RP2040_Zero.scad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]
